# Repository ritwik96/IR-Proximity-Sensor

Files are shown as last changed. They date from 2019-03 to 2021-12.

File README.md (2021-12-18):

# IR-Proximity-Sensor
Tunable IR based proximity sensor with a digital output

<ul>
<li>Autodesk Eagle .brd and .sch files included with all non-standard libs</li>
<li>Sample Arduino code also for tuning and testing included</li>
<li>Potentiometer used to adjust the range</li>
<li>Detection range of about 9cm (3.5 in)</li>
</ul>
<p><strong>Important Notes:</strong></p>
<ul class="remarkup-list">
<li class="remarkup-list-item">The 220 &Omega; resistor is a pull-up in parallel with the LED. The LED needs to be one with an internal resistance (Standard RED 5mm LED with internal resistance is recommended)</li>
<li class="remarkup-list-item">The board has a normal HIGH and triggered LOW. The LED will be ON when the sensor hasn't been triggered and will turn OFF when it has.</li>
</ul>
<br>
<br>
<b> BOM: </b>
<table style="width: 340px;">
<tbody>
<tr>
<td style="width: 224px;">
<p><strong>Part</strong></p>
</td>
<td style="width: 90px;">
<p><strong>Part no.</strong></p>
</td>
<td style="width: 25px;">
<p><strong>Quantity</strong></p>
</td>
</tr>
<tr>
<td style="width: 224px;">
<p>IR Reflective Sensor</p>
</td>
<td style="width: 90px;">
<p>TCRT 5000</p>
</td>
<td style="width: 25px;">
<p>1</p>
</td>
</tr>
<tr>
<td style="width: 224px;">
<p>Red LED (internal resistor)</p>
</td>
<td style="width: 90px;">&nbsp;</td>
<td style="width: 25px;">
<p>1</p>
</td>
</tr>
<tr>
<td style="width: 224px;">
<p>100 ohm Resistor</p>
</td>
<td style="width: 90px;">&nbsp;</td>
<td style="width: 25px;">
<p>1</p>
</td>
</tr>
<tr>
<td style="width: 224px;">
<p>220 ohm Resistor</p>
</td>
<td style="width: 90px;">&nbsp;</td>
<td style="width: 25px;">
<p>1</p>
</td>
</tr>
<tr>
<td style="width: 224px;">
<p>4.7k ohm Resistor</p>
</td>
<td style="width: 90px;">&nbsp;</td>
<td style="width: 25px;">
<p>1</p>
</td>
</tr>
<tr>
<td style="width: 224px;">
<p>10k Multi-turn POT</p>
</td>
<td style="width: 90px;">&nbsp;</td>
<td style="width: 25px;">
<p>1</p>
</td>
</tr>
<tr>
<td style="width: 224px;">
<p>0.1uF Ceramic Capacitor</p>
</td>
<td style="width: 90px;">&nbsp;</td>
<td style="width: 25px;">
<p>2</p>
</td>
</tr>
<tr>
<td style="width: 224px;">
<p>TL081 op-amp</p>
</td>
<td style="width: 90px;">
<p>TL081</p>
</td>
<td style="width: 25px;">
<p>1</p>
</td>
</tr>
<tr>
<td style="width: 224px;">
<p>LM311N op-amp</p>
</td>
<td style="width: 90px;">
<p>LM311N</p>
</td>
<td style="width: 25px;">
<p>1</p>
</td>
</tr>
<tr>
<td style="width: 224px;">
<p>Break Away Headers</p>
</td>
<td style="width: 90px;">&nbsp;</td>
<td style="width: 25px;">
<p>6</p>
</td>
</tr>
</tbody>
</table>
<br>
<br>
<b> Schematic </b>
<p><img src="https://lh3.googleusercontent.com/fife/AAWUweXJ0cqJTT9yQKcJLtwWGiwWtPHNEDslHPKHX4X1kVe6rQgvylilLF-veRYypt4GBSyLvxIxgf_NBnjHtnxn2Fl2rCG9K_CXedOrj_bJrCb9PioXvAnjB80D2a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" alt="Schematic" /></p>
<br>
<br>
<b> Prototype Board </b>
<p>Prototype Board</p>
<br>
<br>
<b> BreadBoard based testing </b>
<p>Prototype Board</p>
<br>
<br>

OSH Park Project Link:

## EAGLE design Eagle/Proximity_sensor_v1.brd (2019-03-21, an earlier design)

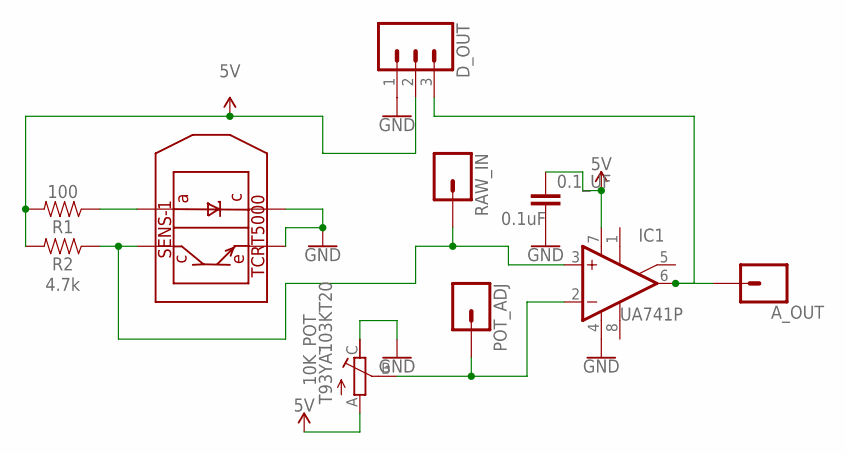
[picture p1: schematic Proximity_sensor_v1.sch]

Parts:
0.1_UF: 0.1uF; CAP-PTH-SMALL-KIT
10K_POT: T93YA103KT20; TRIM_T93YA103KT20
A_OUT: CONN_01; 1X01
D_OUT: CONN_03; 1X03
IC1: UA741P; DIL08
POT_ADJ: CONN_01; 1X01
R1: 100; AXIAL-0.3-KIT
R2: 4.7k; AXIAL-0.3-KIT
RAW_IN: CONN_01; 1X01
SENS-1: TCRT5000; 5000

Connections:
5V: 0.1_UF.1, 10K_POT.A, D_OUT.2, IC1.7 (V+), R1.P$2 (2), R2.P$2 (2)
GND: 0.1_UF.2, 10K_POT.C, D_OUT.1, IC1.4 (V-), SENS-1.P$2, SENS-1.P$4
unnamed: R1.P$1 (1), SENS-1.P$3
unnamed: 10K_POT.B, IC1.2 (-IN), POT_ADJ.1
unnamed: A_OUT.1, D_OUT.3, IC1.6 (OUT)
unnamed: IC1.3 (+IN), R2.P$1 (1), RAW_IN.1, SENS-1.P$1

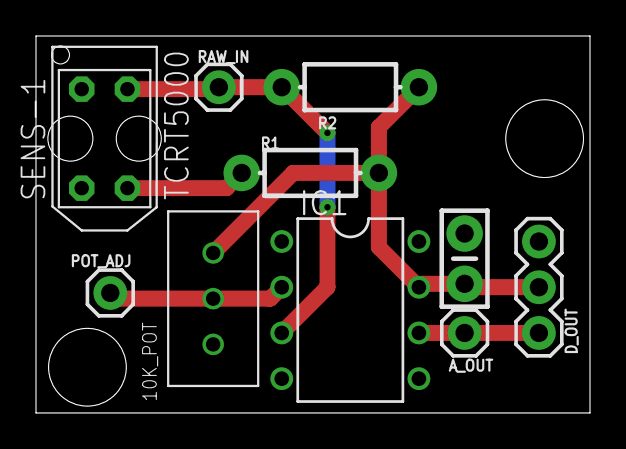
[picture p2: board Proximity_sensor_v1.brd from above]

Board: 2 copper layers, 30.8 x 20.9 mm, 10 parts (0 on the bottom side), 6 nets.

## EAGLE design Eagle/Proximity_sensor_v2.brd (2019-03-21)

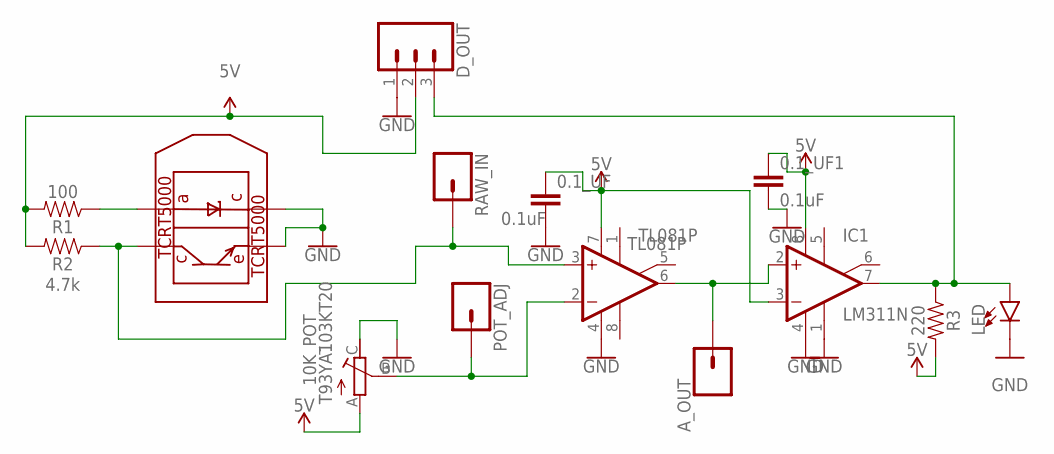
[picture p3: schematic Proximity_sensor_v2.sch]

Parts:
0.1_UF, 0.1_UF1: 0.1uF; CAP-PTH-SMALL-KIT
10K_POT: T93YA103KT20; TRIM_T93YA103KT20
A_OUT: CONN_01; 1X01
D_OUT: CONN_03; 1X03
IC1: LM311N; DIL08
LED: LED5MM; LED_5MM
POT_ADJ: CONN_01; 1X01
R1: 100; AXIAL-0.3-KIT
R2: 4.7k; AXIAL-0.3-KIT
R3: 220; AXIAL-0.3-KIT
RAW_IN: CONN_01; 1X01
TCRT5000: TCRT5000; 5000
TL081P: TL081P; DIL08

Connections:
5V: 0.1_UF.1, 0.1_UF1.1, 10K_POT.A, D_OUT.2, IC1.3 (-IN), IC1.8 (V+), R1.P$2 (2), R2.P$2 (2), R3.P$2 (2), TL081P.7 (V+)
A_OUT: A_OUT.1, IC1.2 (+IN), TL081P.6 (OUT)
GND: 0.1_UF.2, 0.1_UF1.2, 10K_POT.C, D_OUT.1, IC1.1 (GND), IC1.4 (V-), LED.K (C), TCRT5000.P$2, TCRT5000.P$4, TL081P.4 (V-)
OUTPUT: D_OUT.3, IC1.7 (OUT), LED.A, R3.P$1 (1)
RAW: R2.P$1 (1), RAW_IN.1, TCRT5000.P$1, TL081P.3 (+IN)
REF: 10K_POT.B, POT_ADJ.1, TL081P.2 (-IN)
SOURCING: R1.P$1 (1), TCRT5000.P$3

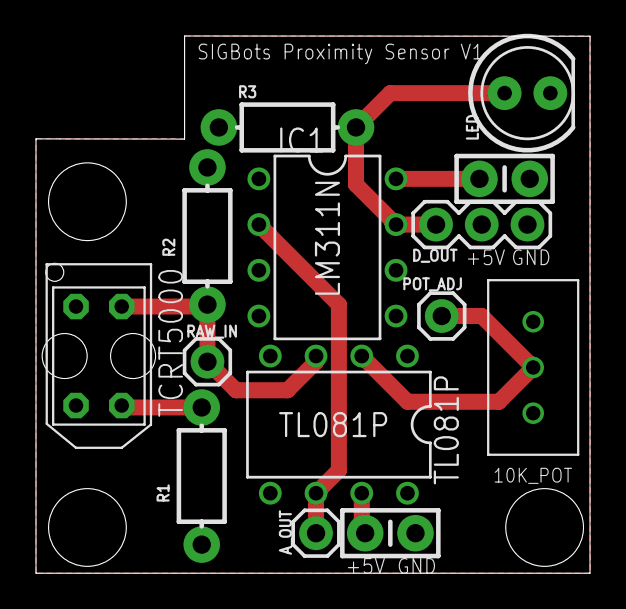
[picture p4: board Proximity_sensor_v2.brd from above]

Board: 2 copper layers, 30.8 x 29.8 mm, 14 parts (0 on the bottom side), 7 nets.

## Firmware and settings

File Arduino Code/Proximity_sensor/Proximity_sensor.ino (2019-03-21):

int count=0;
float V_A0;                                     //  Pot Voltage
float V_A1;                                     //  Pre Op-Amp Voltage
float V_A2;                                     //  Post Op-Amp Voltage
int V_D52;                                     //  Post Op-Amp Voltage (Digital)
void setup()
{
  Serial.begin(9600); 
}

void loop()
{

  V_A0 = (analogRead(A0) * 5) / 1.024;        //  Pot Voltage milivolt scale      
  V_A1 = (analogRead(A1) * 5) / 1.024;        //  Pre Op-Amp Voltage milivolt scale      
  V_A2 = (analogRead(A2) * 5) / 1.024;        //  Post Op-Amp Voltage 
  V_D52 = digitalRead(52) * 5000;             //  Post Op-Amp Voltage (Digital Read) 0-5000 scale     

  Serial.print(V_A0);                         //  Pot Voltage
  Serial.print("\t");                         //tab
  Serial.print(V_A1);                         //  Pre Op-Amp Voltage
  Serial.print("\t");                         //tab
  Serial.print(V_A2);                         //  Post Op-Amp Voltage
  Serial.print("\t");                         //tab
  Serial.println(V_D52);                      //  Post Op-Amp Voltage (Digital)  
}

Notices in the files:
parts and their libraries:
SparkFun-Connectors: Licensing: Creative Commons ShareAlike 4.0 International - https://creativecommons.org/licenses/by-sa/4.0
